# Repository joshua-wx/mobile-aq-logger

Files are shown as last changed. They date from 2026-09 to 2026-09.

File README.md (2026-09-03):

# AQ Rapid Sampler

A portable air-quality logger built on an ESP32-S3 running MicroPython. A
Sensirion SEN65 samples particulate matter and gas indices once a second; a
battery-backed PCF8523 real-time clock timestamps every row; readings go to a
CSV file on the board's flash.

The device has no WiFi and no web server. Its whole interface is a
line-oriented JSON protocol on the USB serial port, and one dashboard —
[`aq_bridge.py`](aq_bridge.py) on a host computer at `http://127.0.0.1:9876` —
both displays it and drives it:

| | |
|---|---|
| **Display** | Live readings, the last 200 samples, 30-minute plots of every variable |
| **Control** | Start/stop logging, set location, set the clock, download (one file or all of them) and delete log files |

Logging does not need the host. Location and the autostart flag are persisted
on the device, so a board configured at the bench can be unplugged and run on
battery; a run already in progress continues when the USB cable comes out.

---

## Hardware

ESP32-S3 with two devices on I2C bus 0 at 100 kHz:

```
ESP32-S3            SEN65        PCF8523
--------            -----        -------
GPIO 5  ---- SDA ---- SDA -------- SDA
GPIO 6  ---- SCL ---- SCL -------- SCL
3V3     ---- VCC ---- VCC -------- VCC
GND     ---- GND ---- GND -------- GND
                                   + CR1220 backup cell
```

| Device | Address |
|---|---|
| SEN65 | `0x6B` |
| PCF8523 | `0x68` |

**The PCF8523 and a DS3231 cannot share the bus** — both live at `0x68`. This
project used a DS3231 previously; that support has been removed.

### Two PCF8523 defaults that will bite you

The chip powers up with settings that are wrong for this application, so
[`pcf8523.py`](pcf8523.py) fixes both when you construct the driver:

- **Battery switch-over is disabled** out of reset (`PM = 111`). Until it is
  configured the coin cell does nothing and the clock resets on every power
  cycle. The driver enables standard-mode switch-over with battery-low
  detection, which is correct for a 3.3 V rail and a 3 V cell.
- **CLKOUT runs at 32.768 kHz** out of reset, draining the backup cell for no
  benefit here. The driver turns it off.

⚠️ **Check the crystal on your breakout** and pass `cap_12p5pf=True` (12.5 pF,
e.g. Adafruit's board) or `False` (7 pF). Getting this wrong costs tens of ppm
of timekeeping accuracy.

---

## Files

| File | Role |
|---|---|
| [`main.py`](main.py) | The application. Sampling, logging, clock, and the USB serial protocol. Runs on boot |
| [`sen65.py`](sen65.py) | SEN65 driver, ported from Sensirion's Arduino library |
| [`pcf8523.py`](pcf8523.py) | PCF8523 RTC driver |
| [`aq_bridge.py`](aq_bridge.py) | **Host-side.** Speaks the serial protocol and serves the dashboard |
| [`log_aq.py`](log_aq.py) | Headless alternative to `main.py` — logs to CSV with no host interface at all |
| [`postprocess.ipynb`](postprocess.ipynb) | **Host-side.** Merges a run's hourly CSVs onto one time axis and plots it |
| [`test_sen65.py`](test_sen65.py) | Bench test: print sensor readings once a second |
| [`test_pcf8523.py`](test_pcf8523.py) | Bench test: print the time; set it with `SET_TIME = True` |
| [`boot.py`](boot.py) | MicroPython boot hook, currently all commented out |

---

## Getting started

### 1. Flash the device

Copy to the board's filesystem with `mpremote`, Thonny, or `ampy`:

```
mpremote cp main.py sen65.py pcf8523.py boot.py :
```

Reset the board. It prints its startup banner and begins sampling.

### 2. Start the dashboard

With the board plugged into the host over USB:

```
pip install pyserial
python3 aq_bridge.py                 # auto-detects the board
```

Open `http://127.0.0.1:9876`. Everything below happens there.

### 3. Set the clock

The RTC ships unset, so the first thing to do is give it the time. The Clock
card shows the device time and its drift against the computer you are sitting
at. With **auto** ticked (the default) the page syncs the RTC by itself
whenever the clock is unset or more than 10 s out; the button does the same on
demand.

If the card says **"clock not set"** and stays that way after a sync, or reports
**"backup battery low"**, fit a fresh CR1220. Without a working cell the
oscillator-stop flag sets on every power-up and the time never survives a
reboot.

Other ways to set it, if browser accuracy is not enough:

- **A GPS module.** Gives sub-second time *and* the latitude/longitude that is
  typed in by hand today. Most hardware, biggest payoff.
- **`test_pcf8523.py`** with `SET_TIME = True`, flashed once, for a bench set.

### 4. Log

Type the location into the Logging card and press **Save** — it is written to
`config.json` on the device and survives a power cycle, so it only has to be
done when the site changes. Then press **Start logging**. Files appear in the
Log files card for download or deletion.

To deploy the board away from a computer, tick **start logging automatically
at power-up** before unplugging it. The device then opens a new log on every
boot with no host attached. Leave it unticked and logging is started by hand
from the dashboard — a run that is already going keeps going when the USB
cable comes out.

A run rolls over to a new file every hour, so a long deployment arrives as a
row of hourly files rather than one that is slow to transfer. **Download all**
collects the whole row in one go — see *Downloading log files*.

---

## Data format

A new file every hour, and one whenever logging starts, named for its own
start time: `YYYYMMDD_HHMMSS.csv`. Rotation keeps an unattended run from
producing one enormous file, and keeps each file individually downloadable
over the serial link. Change `_ROTATE_S` in [`main.py`](main.py) to use a
different interval, or set it to `0` to write one file per run as before.

```
# Location: lat=-37.8136, lon=144.9631
# Start: 2026-09-02 13:26:46  (elapsed_s = 0)
# Clock: PCF8523 RTC, local time
elapsed_s,PM1.0_ug_m3,PM2.5_ug_m3,PM4.0_ug_m3,PM10_ug_m3,VOC_index,NOx_index
0,7.0,8.0,9.0,10.0,106.0,
1,8.0,9.0,10.0,11.0,107.0,
```

- `elapsed_s` is **whole seconds since the `# Start:` time**, one row per
  second. Absolute time is `Start + elapsed_s`; in pandas, for instance:

  ```python
  df = pd.read_csv(path, comment="#")
  t0 = pd.Timestamp("2026-09-02 13:26:46")          # from the header
  df["timestamp"] = t0 + pd.to_timedelta(df.elapsed_s, unit="s")
  ```

  `start + elapsed_s` is exactly the row's wall-clock second: the header time,
  the filename and the offset origin all come from one reading of the clock,
  so hourly files stitch back together without a seam.

- The start time is **local wall-clock with no timezone**.
- Empty fields are readings the sensor did not supply. NOx in particular stays
  blank for the first minutes while its index warms up.
- The `# Clock:` line records whether the start time can be trusted. If the RTC
  is unset or absent it says so explicitly rather than letting you discover it
  later.
- Roughly **64 kB per 35 minutes**, so about 45 hours in 8 MB, split across
  one file per hour of about 110 kB each — less the reserve described below,
  which stops logging before the filesystem is full.
- Every file stands alone: its own location, start time, clock provenance and
  `elapsed_s` origin. Rotation happens *before* the sample that triggers it is
  written, so that sample opens the new file rather than being lost or
  recorded twice — no row falls in a crack between two files.
- A file is never overwritten. If the clock is stopped and hands out a name
  that already exists — the same second on every boot, with a flat RTC — the
  new log becomes `20260902_211719-1.csv`, `-2.csv` and so on rather than
  clobbering what is there.

The column was a full `YYYY-MM-DD HH:MM:SS` timestamp until it became clear it
was ~40% of every row and entirely redundant: at a fixed 1 Hz it is
reconstructible from the start time. That change alone took the same log from
96 kB to 64 kB.

Two clock effects are worth knowing about. The periodic RTC resync can step
the clock by a second or two, and `elapsed_s` follows it — that is the point,
since it is correcting the ESP32's RC drift, so the column tracks real elapsed
time rather than a drifting oscillator. Setting the clock from the dashboard
mid-run does **not** dislocate the column: the logging epoch moves with the
correction, so a run that starts before the clock is set stays continuous.

### When the flash fills up

Logging stops by itself while **128 kB is still free**, rather than running the
filesystem to zero.

The reserve is sized around what is on that filesystem besides data: the
device's own source. `main.py`, `sen65.py`, `pcf8523.py` and `boot.py` come to
about 45 kB together, so 128 kB leaves room to rewrite every one of them over
USB with ~85 kB spare for filesystem metadata and headroom. A flash filled to
the last byte is one you cannot repair without first deleting data — which is
the situation the reserve exists to avoid. It costs 1.6% of an 8 MB flash, or
about 70 minutes of logging out of ~45 hours.

Change `_MIN_FREE_B` in [`main.py`](main.py) to use a different figure. If you
are on a larger flash, or you never intend to reflash over USB, a smaller
reserve is perfectly reasonable — 32 kB still covers filesystem metadata
comfortably.

- Free space is checked **once a minute** while logging, not once a second:
  `statvfs` has to walk filesystem metadata, and a minute of logging is under
  2 kB against a 128 kB reserve, so nothing can slip past between checks.
- **Starting** a log is refused the same way, with the numbers in the reply,
  so a device that cannot log says so rather than appearing to start.
- Sampling, the live stream and the dashboard all keep running. Only writing
  to flash stops.
- The device card shows free space in amber as it approaches the reserve and
  red once logging is barred, and the Logging card shows **STOPPED** with the
  reason rather than an unexplained **IDLE**.
- If `statvfs` is unavailable the check does nothing: the logger will not stop
  on an absence of evidence.

Free some space by downloading and deleting log files from the dashboard, and
logging can start again.

### Reading the gas indices

VOC and NOx are Sensirion index values, not concentrations, and **they do not
share a baseline**:

| | Range | Resting value | Meaning |
|---|---|---|---|
| VOC index | 1–500 | **100** | Moves either side of 100 as VOCs rise and fall |
| NOx index | 1–500 | **1** | Sits at 1 and only climbs when NOx is present |

So a NOx column that reads a constant `1.0` is the sensor saying "no NOx above
baseline" — it is not a fault. In a 35-minute indoor test log, NOx was blank
for 9 s, then 0 for 46 s, then 1.0 for the remaining 2076 samples without once
moving, while VOC climbed from 0 and settled at 100.

Both indices read 0 for about the first minute while the algorithm establishes
itself, and are blank for the first few seconds before that.

### Where time comes from

The PCF8523 seeds the ESP32's internal clock at boot; timestamps are then taken
from the internal clock so the shared I2C bus is not hit once per sample; and
the internal clock is re-synced from the RTC every 10 minutes, because the
ESP32 runs its clock off an RC oscillator that drifts by seconds per hour.

A missing or faulty RTC does not stop the logger. Sampling continues, the
dashboard reports the problem, and the CSV header flags the timestamps as
unreliable.

---

## Postprocessing

An hour per file keeps the device honest and each download small; it also means a
day's run arrives as 24 files that all start their clock at zero.
[`postprocess.ipynb`](postprocess.ipynb) puts them back together:

```
pip install -r requirements-analysis.txt
jupyter lab postprocess.ipynb
```

Point `LOG_DIR` at the folder you unzipped the download into and run the notebook
top to bottom. It recovers each file's start time, location and clock provenance
from its header, turns `elapsed_s` back into absolute time, and merges everything
onto **one continuous time axis** spanning the run.

That axis is built from the cadence the run actually has rather than an assumed
one. A row is written per sensor sample, and the SEN65 does not produce samples on
a perfectly regular beat — a real run comes out around one every two seconds, with
the spacing wandering by a second either way. The notebook measures the typical
interval and treats only a much longer jump as the logger being off, so an hour it
spent switched off is an explicit break every plot honours, while ordinary jitter
is not mistaken for thousands of tiny outages. Set `SAMPLE_PERIOD` to a frequency
like `"1s"` to force a regular grid instead.

It reports the cadence, coverage and gaps, names any file whose `# Clock:` header
the device flagged as unreliable, and draws the run: PM, an hour of PM2.5 zoomed to
individual samples, the gas indices, a panel per variable, an hour-of-day profile
and the distributions, with the WHO 24-hour guideline levels marked. The last cell
writes the merged run out as a single `merged.csv` on that continuous axis, plus an
hourly-mean copy small enough to mail.

---

## The dashboard

On the host computer:

```
pip install pyserial
python3 aq_bridge.py                 # auto-detects the board
```

Then open `http://127.0.0.1:9876`. Device status, logging, the clock and the
location are at the top; live readings, recent samples and plots are tabs
below them.

```
--port /dev/ttyACM0    serial device (default: auto-detect)
--http-port 9876       steps to the next free port if busy
--host 0.0.0.0         let other machines on your network view it
--list                 show candidate serial ports and exit
--no-dtr               see the warning below
--no-map               never fetch map tiles
--tile-cache DIR       where tiles are kept (default: ~/.cache/aq_bridge/tiles)
```

Plot x-axes autoscale to the span of buffered data, clamped between 5 and 30
minutes, with a tick every minute.

⚠️ The dashboard can start and stop logging and **delete files on the device**,
and there is no authentication. It binds to `127.0.0.1` for that reason; only
pass `--host 0.0.0.0` on a network you trust.

### The location map

The Location card shows the saved lat/lon on an OpenStreetMap background, so a
typo in a coordinate is visible rather than something you discover in the data
later. It redraws when the device reports a location — on connection, and
after **Save** — and not on the once-a-second poll.

Tiles are fetched **by the bridge, not by your browser**, and cached under
`~/.cache/aq_bridge/tiles`. That has three consequences worth knowing:

- Displaying a location sends those coordinates to `tile.openstreetmap.org`.
  Nine or so tiles are fetched per location or zoom change, never in bulk, with
  an identifying User-Agent as the [tile usage policy][tup] requires.
- Once an area is cached it keeps working with no connection, so viewing a site
  at the bench means it still draws in the field.
- `--no-map` stops all outbound requests. Cached tiles are still shown; where
  there are none the card falls back to a plain coordinate grid and says so.

The same fallback appears whenever tiles cannot be had — the map is never the
reason you cannot read a coordinate, which is also printed under the card.

[tup]: https://operations.osmfoundation.org/policies/tiles/

### Downloading log files

Log files live on the board's flash — that is what lets it run unattended —
so a download is a transfer over the serial link, not a static file the
browser fetches. Press **Download** and the bridge asks the device for the
file, reassembles the base64 chunks it sends back, checks them against the
byte count and checksum the device reports, and only then hands your browser
a `.csv`. A truncated or corrupted transfer fails with a message instead of
silently saving a short file.

It is not instant: expect a few seconds for a typical log, and longer for a
large one. Sampling and logging continue throughout — the device paces itself
between chunks so a download cannot starve the sensor.

**Download all** does the same for every file on the device and saves them as
a single `aq-logs-<date>-<time>.zip`. It asks the device for a fresh listing
first, so a file opened since the dashboard last refreshed is included, and it
transfers one file at a time — a full flash is minutes of serial, and the Log
files card counts the files off as they arrive. Anything that will not
transfer is left out rather than aborting the run: the zip then carries a
`MISSING.txt` naming those files, and the dashboard says how many were
skipped, so retry them individually with **Download**.

### Serial protocol

`main.py` streams tagged JSON lines and accepts tagged JSON commands on the
same port. Ordinary `print()` diagnostics share it and are ignored by the
reader because they lack the tag.

```
out  AQ1 {"t":"data","ts":"2026-09-02 13:26:45","v":{…},"mx":{…},"mn":{…}}  ~1 Hz
out  AQ1 {"t":"status","lat":-37.8,"logging":true,…}      every 5 s + on change
out  AQ1 {"t":"ack","id":7,"ok":true,"msg":"started"}              per command
out  AQ1 {"t":"file","id":8,"seq":0,"d":"<base64>"}          during a download
in   AQC {"id":7,"cmd":"log_start"}
```

`data` carries the latest / max / 1-minute-mean triple the tables show.
`status` carries configuration, which changes rarely. Every command draws
exactly one `ack` echoing its `id`, so replies can be matched to requests
even though sample records are interleaved with them.

| Command | Fields | Does |
|---|---|---|
| `ping` | — | Liveness check |
| `status` | — | Ask for a `status` record now |
| `list` | — | Files and their sizes |
| `log_start` / `log_stop` | — | Begin or end a logging run |
| `set_loc` | `lat`, `lon` | Set the location and persist it |
| `set_clock` | `ts` (`YYYY-MM-DDTHH:MM:SS`) | Set the RTC and the ESP32 clock |
| `autostart` | `on` | Log automatically at power-up |
| `delete` | `name` | Remove a log file |
| `get` | `name`, `off` | Stream a log file back |

Set `_SERIAL_STREAM = False` in `main.py` to silence the outgoing stream.

**Never send `0x03` (Ctrl-C) on this port.** MicroPython treats it as an
interrupt and would stop the logger. For the same reason, do not leave a REPL
(Thonny, `mpremote`) attached while the bridge is running.

### Persisted configuration

Location and the autostart flag are kept in `config.json` on the device, and
`main.py` reloads them at boot. Deleting that file restores the defaults
compiled into `main.py`.

## Troubleshooting

**Config section fills but the tables and plots stay empty, or data appears
only every few tens of seconds.**
DTR is not asserted. On the ESP32-S3's native USB CDC, DTR is how the host says
"I am listening"; with it low MicroPython treats stdout as disconnected and
truncates it. The signature is lines like `AQ12.2, "pm4p0": 2.8,` — no space
after the tag, starting mid-record. The bridge asserts DTR by default, so this
only happens if you passed `--no-dtr`. Measured on the bench: DTR low gave 0
parseable records in 12 s, DTR high gave 14 with zero errors.

**Garbled lines, or "device reports readiness to read but returned no data".**
Two programs are reading the port. Linux lets several processes open the same
tty and then splits the bytes between them, corrupting every line for all of
them — and an `open()` test cannot detect this, because it succeeds anyway.
Close Thonny, `mpremote`, and any second bridge. The bridge now opens the port
exclusively, so a second copy fails cleanly instead of stealing bytes.

**`OSError: [Errno 98] Address already in use`.**
Something else on the machine holds the HTTP port. Find it with
`ss -ltnp | grep :9876`, or just pass `--http-port`.

**The `# Start:` line reads `2000-01-01`.**
The RTC has never been set, or its backup cell is flat, so the ESP32 is running
from its power-on epoch. See *Set the clock* above. A board deployed with
autostart and a flat cell will still log, and `elapsed_s` is still correct —
only the origin is unknown, and the `# Clock:` line says so.

**Buttons do nothing, or say "no reply from the device in 5 s".**
The device is streaming but not reading commands. Check that nothing else is
holding the port (a REPL will swallow the command bytes), and that `main.py`
is actually running rather than the board sitting at the REPL prompt after a
Ctrl-C.

**Logging stopped on its own and the card says "storage low".**
The flash reached the 128 kB reserve. Download what you want to keep and delete
some log files; logging will start again once there is room. See *When the
flash fills up*.

**A download fails with "transfer stalled" or "checksum mismatch".**
Bytes were lost on the way. Nothing was written to disk — press Download
again. Persistent failures usually mean a second reader on the port. After a
**Download all**, the same failure shows as a file missing from the zip and
named in its `MISSING.txt`.

**`PCF8523 not responding at 0x68`.**
Check wiring. Remember a DS3231 on the bus would answer at the same address.

---

## Known limitations

- Times are local wall-clock with **no timezone recorded**. A log moved between
  machines carries no indication of which offset it was taken in.
- **The device cannot be configured in the field.** With the WiFi dashboard
  gone, setting the clock or the location needs a computer and a USB cable;
  a phone will not do. Configure at the bench, and rely on `config.json` and
  the autostart flag once deployed. Only start/stop is lost in the field, and
  autostart covers the common case.
- The bridge has **no authentication**, so it binds to localhost by default.
- The map is a fixed north-up view with zoom buttons; it cannot be panned, and
  clicking it does not set the location.
- Location is entered by hand, not sensed.
- The SEN65 also reports **temperature and relative humidity**, which the driver
  exposes but nothing currently logs or displays.
- Browser sync sets the clock to about a second; there is no round-trip latency
  compensation.
- Downloads transfer the whole file each time. `get` accepts an `off` offset so
  a resume is possible, but the dashboard does not use it.

---

## Licence

[MIT](LICENSE).

[`sen65.py`](sen65.py) is a port of Sensirion's Arduino I2C library for the
SEN6x family; command IDs, execution delays and scaling factors come from their
published driver. Sensirion's originals are BSD-3-Clause.

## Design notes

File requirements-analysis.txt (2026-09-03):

# Host-side only, for postprocess.ipynb. Nothing here is installed on the ESP32,
# and none of it is needed to run the logger or the dashboard.
pandas>=2.0
matplotlib>=3.7
jupyterlab>=4.0

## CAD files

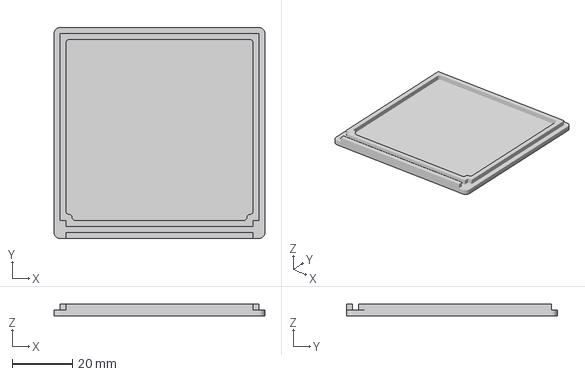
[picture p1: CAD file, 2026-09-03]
case/sen66caselid.3mf
70.0 x 70.0 x 4.00 mm

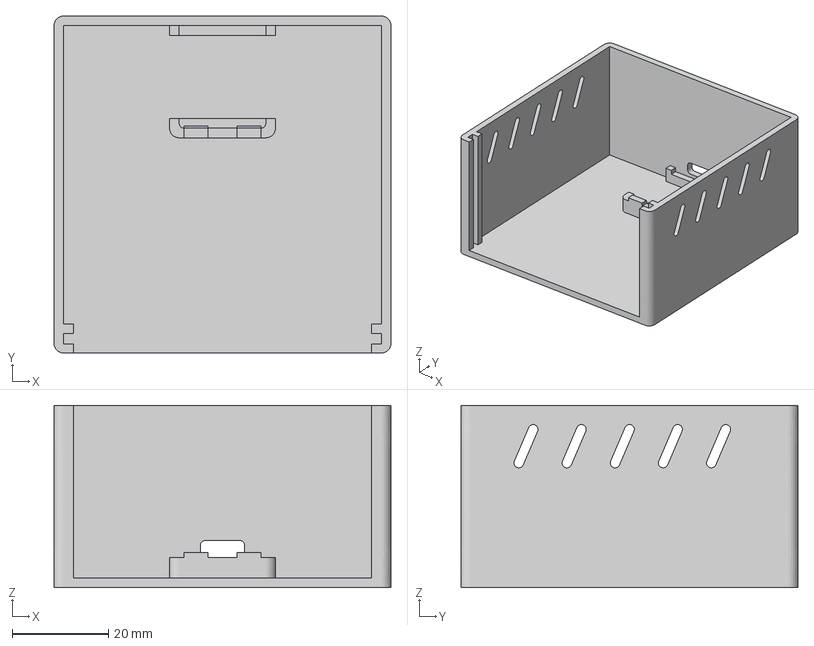
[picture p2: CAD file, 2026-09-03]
case/sen66casebase.3mf
70.0 x 70.0 x 37.9 mm

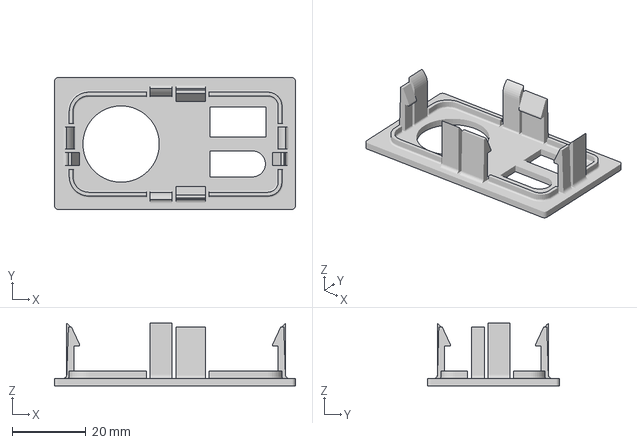
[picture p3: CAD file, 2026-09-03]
case/sen66bracket.3mf
65.5 x 35.9 x 17.0 mm

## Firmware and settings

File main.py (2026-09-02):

"""
AQ-logger — MicroPython air-quality logger for ESP32-S3.

Samples a Sensirion SEN65 once a second, timestamps every row from a
battery-backed PCF8523 RTC, and appends to a CSV file on the board's flash.
A new file is started every hour so an unattended run does not produce one
unbounded file; see _ROTATE_S.

There is no WiFi and no web server here. The device's entire interface is a
line-oriented protocol on the USB serial port: it streams tagged JSON out and
accepts tagged JSON commands in. aq_bridge.py on a host computer speaks that
protocol and serves the one dashboard, which both displays readings and
configures the device — location, clock, start/stop logging, and downloading
or deleting log files.

Logging does not need the host. Configuration is persisted to config.json, so
a device set up at the bench keeps its location and, if autostart is enabled,
begins logging by itself on power-up. Unplugging the host does not interrupt
a run in progress.

Wire format. One record per line, so a reader can use readline() and ignore
anything it does not recognise:

    out   AQ1 {"t":"data","ts":"...","v":{...},"mx":{...},"mn":{...}}  ~1 Hz
    out   AQ1 {"t":"status","lat":-37.8,"logging":true,...}       every 5 s
    out   AQ1 {"t":"ack","id":7,"ok":true,"msg":"started"}      per command
    out   AQ1 {"t":"file","id":8,"seq":0,"d":"<base64>"}     during download
    in    AQC {"id":7,"cmd":"log_start"}

Ordinary print() diagnostics share the port; they simply lack the tag.

Never send 0x03 (Ctrl-C) on this port: MicroPython treats it as an interrupt
and would stop the logger. Commands are plain ASCII JSON lines.

Wiring (I2C bus 0):
    SDA -> GPIO 5
    SCL -> GPIO 6
    SEN65 at 0x6B, PCF8523 at 0x68
"""

try:
    import asyncio
except ImportError:
    import uasyncio as asyncio   # MicroPython < 1.19

try:
    import json
except ImportError:
    import ujson as json

try:
    import select
except ImportError:
    import uselect as select

try:
    import binascii
except ImportError:
    import ubinascii as binascii

import os
import sys
import time
from machine import I2C, Pin, RTC

from pcf8523 import PCF8523
from sen65 import SEN65

# ---------------------------------------------------------------------------
# Constants
# ---------------------------------------------------------------------------

_KEYS       = ('pm1p0', 'pm2p5', 'pm4p0', 'pm10p0', 'voc', 'nox')
# Rows carry seconds elapsed since '# Start:' in the header rather than a
# full timestamp: at 1 Hz the absolute time was ~40% of every row and is
# entirely reconstructible from the start time plus the offset.
_CSV_HEADER = 'elapsed_s,PM1.0_ug_m3,PM2.5_ug_m3,PM4.0_ug_m3,PM10_ug_m3,VOC_index,NOx_index\n'

_ROTATE_S    = 3600     # start a new log file this often; 0 disables rotation

# Stop logging while this much of the filesystem is still free. The board's
# own source lives on that filesystem — main.py, sen65.py, pcf8523.py and
# boot.py are ~45 kB together — so the reserve is sized to let every one of
# them be rewritten over USB, with the rest as headroom for filesystem
# metadata. Filling the flash completely would leave no room to repair the
# device without first deleting data. Costs ~1.6% of an 8 MB flash.
_MIN_FREE_B    = 128 * 1024
_SPACE_CHECK_S = 60     # how often to look at free space while logging
_RESYNC_S    = 600      # re-read the PCF8523 into the ESP32 clock this often
_DRIFT_WARN  = 2        # seconds of MCU-vs-RTC drift worth printing

_SERIAL_STREAM   = True   # emit tagged JSON lines on USB serial
_SERIAL_TAG      = 'AQ1'  # prefix on every line this device emits
_CMD_TAG         = 'AQC'  # prefix the host puts on every command
_SERIAL_STATUS_S = 5      # seconds between unsolicited 'status' records

_CONFIG_FILE = 'config.json'

# File download tuning. 512 raw bytes become a ~700-character line; the pause
# hands the scheduler back to the sensor task between chunks so a download
# cannot starve sampling, and keeps the USB CDC buffer from backing up into a
# blocking write.
_CHUNK        = 512
_CHUNK_PAUSE  = 4         # ms between chunks
_CMD_MAX_LINE = 512       # longest command line accepted, then resynchronise

# ---------------------------------------------------------------------------
# Global state
# ---------------------------------------------------------------------------

_g = {
    'latest':  {k: None for k in _KEYS},
    'max':     {k: None for k in _KEYS},
    'ring':    [],        # last <=60 readings for 1-min mean
    'logging': False,
    'logfile': None,
    'log_t0': None,       # time.time() at the start of the current run
    'stop_reason': '',    # why logging last stopped, '' if by request
    'space_at': 0,        # when free space was last checked
    'ts':      '--',
    'lat':     -37.8136,
    'lon':     144.9631,
    'autostart': False,   # begin logging at boot without a host attached
    'boot_ms': 0,
    'rtc':     None,      # PCF8523 instance, or None if it did not answer
    'rtc_ok':  False,     # False while the RTC reports a stopped oscillator
    'batt_low': False,
    'sending': False,     # a file download is in flight
}

# ---------------------------------------------------------------------------
# Helpers
# ---------------------------------------------------------------------------

def _fmt(v):
    return '' if v is None else '{:.1f}'.format(v)

def _timestamp(t=None):
    """Local wall-clock time as 'YYYY-MM-DD HH:MM:SS'.

    Takes an optional epoch so a log's header, filename and elapsed_s origin
    can all be derived from one instant; reading the clock three times risks
    the second ticking between them, which would put every reconstructed row
    time out by one.
    """
    y, mo, d, h, mi, s = (time.localtime() if t is None else time.localtime(t))[:6]
    return '{:04d}-{:02d}-{:02d} {:02d}:{:02d}:{:02d}'.format(y, mo, d, h, mi, s)

def _filename(t=None):
    y, mo, d, h, mi, s = (time.localtime() if t is None else time.localtime(t))[:6]
    return '{:04d}{:02d}{:02d}_{:02d}{:02d}{:02d}.csv'.format(y, mo, d, h, mi, s)

def _compute_mean(ring):
    if not ring:
        return {k: None for k in _KEYS}
    out = {}
    for k in _KEYS:
        vals = [r[k] for r in ring if r[k] is not None]
        out[k] = round(sum(vals) / len(vals), 1) if vals else None
    return out

def _round1(d):
    return {k: (round(v, 1) if v is not None else None) for k, v in d.items()}

def _list_files():
    """[[name, bytes], ...] for every CSV on flash, oldest name first."""
    out = []
    for f in sorted(os.listdir()):
        if f.endswith('.csv'):
            try:
                out.append([f, os.stat(f)[6]])
            except OSError:
                pass
    return out

def _free_bytes():
    try:
        st = os.statvfs('/')
        return st[0] * st[3]
    except (OSError, AttributeError):
        return None

# ---------------------------------------------------------------------------
# Persisted configuration
#
# With the WiFi dashboard gone the device cannot be reconfigured in the
# field, so what was typed in at the bench has to survive a power cycle.
# ---------------------------------------------------------------------------

def _load_config():
    try:
        with open(_CONFIG_FILE) as fh:
            cfg = json.load(fh)
    except (OSError, ValueError):
        return
    for key in ('lat', 'lon'):
        v = cfg.get(key)
        if isinstance(v, (int, float)):
            _g[key] = float(v)
    _g['autostart'] = bool(cfg.get('autostart', False))

def _save_config():
    try:
        with open(_CONFIG_FILE, 'w') as fh:
            json.dump({'lat': _g['lat'], 'lon': _g['lon'],
                       'autostart': _g['autostart']}, fh)
        return True
    except OSError as e:
        print('Config save failed:', e)
        return False

# ---------------------------------------------------------------------------
# Serial output
# ---------------------------------------------------------------------------

def _emit(kind, obj):
    if not _SERIAL_STREAM:
        return
    obj['t'] = kind
    try:
        print(_SERIAL_TAG, json.dumps(obj))
    except Exception as e:      # a blocked port must never stop the logger
        print('Serial emit failed:', e)


def _emit_status():
    _emit('status', {
        'ts':          _timestamp(),
        'lat':         _g['lat'],
        'lon':         _g['lon'],
        'logging':     _g['logging'],
        'logfile':     _g['logfile'] or '',
        'autostart':   _g['autostart'],
        'stop_reason': _g['stop_reason'],
        'min_free':    _MIN_FREE_B,
        'rtc_present': _g['rtc'] is not None,
        'rtc_ok':      _g['rtc_ok'],
        'batt_low':    _g['batt_low'],
        'files':       _list_files(),
        'free':        _free_bytes(),
        'up':          time.ticks_diff(time.ticks_ms(), _g['boot_ms']) // 1000,
    })


def _ack(cid, ok, msg, data=None):
    rec = {'id': cid, 'ok': ok, 'msg': msg}
    if data is not None:
        rec['data'] = data
    _emit('ack', rec)


async def _status_task():
    while True:
        _emit_status()
        await asyncio.sleep(_SERIAL_STATUS_S)


# ---------------------------------------------------------------------------
# Clock
# ---------------------------------------------------------------------------

def _open_rtc(i2c):
    """Attach to the PCF8523 and seed the ESP32 clock from it.

    A missing or faulty RTC must not stop the logger: the sensor still runs
    and the dashboard reports the problem, timestamps just start from
    whatever the ESP32 booted with until the host sets the clock.
    """
    try:
        rtc = PCF8523(i2c)
    except OSError as e:
        print('WARNING: PCF8523 not responding at 0x68 ({}) - running without it.'.format(e))
        return None

    _g['rtc'] = rtc
    if not _sync_mcu_clock(rtc):
        print('WARNING: PCF8523 oscillator stopped - time is not trustworthy.')
        print('         Connect the host bridge and sync the clock.')
    if _g['batt_low']:
        print('WARNING: PCF8523 backup battery is low - replace the cell.')
    return rtc


def _sync_mcu_clock(rtc):
    """Copy RTC -> ESP32 internal clock. Returns True if the time is valid.

    The ESP32 runs its clock off an RC oscillator that drifts by seconds per
    hour, so this is called periodically, not just at boot.
    """
    try:
        _g['rtc_ok']   = not rtc.lost_power()
        _g['batt_low'] = rtc.battery_low()
        if _g['rtc_ok']:
            RTC().datetime(rtc.datetime())
    except OSError as e:
        print('RTC read failed:', e)
        return False
    return _g['rtc_ok']


def _set_clock(rtc, dt):
    """Set both the PCF8523 and the ESP32 clock from an 8-tuple."""
    before = int(time.time())
    RTC().datetime(dt)
    # Setting the clock redefines the time base — often by years, when the
    # RTC was unset. Carry the logging epoch along with it so elapsed_s stays
    # continuous instead of jumping the width of the correction. The periodic
    # RTC resync is deliberately not compensated: those steps are the drift
    # correction, and elapsed_s should follow them.
    if _g['log_t0'] is not None:
        _g['log_t0'] += int(time.time()) - before
    if rtc is not None:
        rtc.datetime(dt)
        _g['rtc_ok']   = not rtc.lost_power()
        _g['batt_low'] = rtc.battery_low()
    return _g['rtc_ok']


async def _clock_task():
    """Pull the ESP32 clock back onto the RTC every _RESYNC_S seconds."""
    while True:
        await asyncio.sleep(_RESYNC_S)
        rtc = _g['rtc']
        if rtc is None:
            continue
        try:
            before = time.time()
            if _sync_mcu_clock(rtc):
                drift = time.time() - before
                if abs(drift) >= _DRIFT_WARN:
                    print('Clock resync: stepped MCU clock by {:+d} s'.format(drift))
        except Exception as e:
            print('Clock resync failed:', e)


# ---------------------------------------------------------------------------
# Radio
# ---------------------------------------------------------------------------

def _radio_off():
    """Shut the WiFi down. Nothing uses it, and this is a battery device.

    The interface state can survive a soft reset, so an AP left running by a
    previous firmware would otherwise keep drawing current forever.
    """
    try:
        import network
        for iface in (network.AP_IF, network.STA_IF):
            w = network.WLAN(iface)
            if w.active():
                w.active(False)
    except Exception as e:
        print('Could not disable WiFi:', e)


# ---------------------------------------------------------------------------
# Logging
# ---------------------------------------------------------------------------

def _open_log():
    """Create a new CSV, write its header, and make it the active log.

    Returns (filename, message), or (None, reason) if it could not be
    opened. Every file is self-contained: its own location, start time and
    clock provenance, with elapsed_s counting from zero again.
    """
    free = _free_bytes()
    if free is not None and free < _MIN_FREE_B:
        return None, 'storage low: {} kB free, {} kB reserved'.format(
            free // 1024, _MIN_FREE_B // 1024)
    # One instant for the name, the header and the elapsed_s origin, kept as
    # whole seconds so that start + elapsed_s is exactly the row's wall clock.
    t0 = int(time.time())
    fname = _filename(t0)
    # A stopped RTC hands out the same name on every boot, which would
    # otherwise silently overwrite the previous run's data.
    stem, n = fname[:-4], 1
    while n < 100:
        try:
            os.stat(fname)
        except OSError:
            break                       # the name is free
        fname = '{}-{}.csv'.format(stem, n)
        n += 1
    try:
        with open(fname, 'w') as fh:
            if _g['lat'] is not None:
                fh.write('# Location: lat={}, lon={}\n'.format(_g['lat'], _g['lon']))
            fh.write('# Start: {}  (elapsed_s = 0)\n'.format(_timestamp(t0)))
            # Timestamps are local wall-clock with no timezone, so record
            # where they came from and whether they can be believed.
            if _g['rtc'] is None:
                clock = 'ESP32 internal only, no RTC - times unreliable'
            elif not _g['rtc_ok']:
                clock = 'PCF8523 RTC NOT SET - times unreliable'
            else:
                clock = 'PCF8523 RTC, local time'
            fh.write('# Clock: {}\n'.format(clock))
            fh.write(_CSV_HEADER)
    except OSError as e:
        print('Could not open log file:', e)
        return None, str(e)
    _g['logfile'] = fname
    _g['log_t0']  = t0
    return fname, 'started'


def _start_logging():
    if _g['logging']:
        return _g['logfile'], 'already logging'
    fname, msg = _open_log()
    if fname is None:
        return None, msg
    _g['logging'] = True
    _g['stop_reason'] = ''
    _g['space_at'] = time.time()
    print('Logging started:', fname)
    return fname, msg


def _stop_logging(reason=''):
    """Stop the run. `reason` is empty when a person asked for it."""
    if _g['logging']:
        print('Logging stopped:', _g['logfile'],
              '({})'.format(reason) if reason else '')
        _g['logging'] = False
        _g['stop_reason'] = reason


# ---------------------------------------------------------------------------
# Commands
#
# One JSON object per line, tagged so that terminal noise and half-typed
# input are ignored rather than misread:
#
#     AQC {"id":7,"cmd":"log_start"}
#
# Every command draws exactly one 'ack' carrying the same id, so the host can
# match replies to requests even though status and data records are
# interleaved with them. 'get' acks first and then streams 'file' records.
# ---------------------------------------------------------------------------

def _cmd_set_loc(c):
    try:
        lat = float(c['lat'])
        lon = float(c['lon'])
    except (KeyError, TypeError, ValueError):
        return False, 'invalid lat/lon', None
    if not (-90.0 <= lat <= 90.0) or not (-180.0 <= lon <= 180.0):
        return False, 'lat/lon out of range', None
    _g['lat'] = lat
    _g['lon'] = lon
    saved = _save_config()
    return True, 'saved {:.6f}, {:.6f}{}'.format(
        lat, lon, '' if saved else ' (not persisted)'), None


def _cmd_set_clock(c):
    try:
        s = c['ts']                    # "2026-06-11T14:30:00"
        date, t = s.split('T')
        y, mo, d = date.split('-')
        h, mi, sec = t.split(':')
        dt = (int(y), int(mo), int(d), 0, int(h), int(mi), int(sec), 0)
    except (KeyError, TypeError, ValueError, AttributeError) as e:
        return False, 'invalid datetime: ' + str(e), None

    try:
        ok = _set_clock(_g['rtc'], dt)
    except (OSError, ValueError) as e:
        return False, 'RTC write failed: ' + str(e), None

    print('Clock set to:', s)
    if _g['rtc'] is None:
        return True, 'ESP32 clock set (no RTC): ' + s, None
    if not ok:
        return False, 'RTC written but oscillator still stopped - check the battery', None
    return True, 'clock set: ' + s, None


def _cmd_autostart(c):
    _g['autostart'] = bool(c.get('on'))
    saved = _save_config()
    return (saved,
            'autostart {}{}'.format('on' if _g['autostart'] else 'off',
                                    '' if saved else ' (not persisted)'),
            None)


def _cmd_delete(c):
    name = c.get('name')
    if not isinstance(name, str) or '/' in name or not name.endswith('.csv'):
        return False, 'invalid filename', None
    if _g['logging'] and _g['logfile'] == name:
        return False, 'cannot delete the active log file', None
    try:
        os.remove(name)
    except OSError:
        return False, 'not found', None
    print('Deleted:', name)
    return True, 'deleted ' + name, None


async def _send_file(cid, c):
    """Stream one CSV back as base64 'file' records, then an eof record.

    The host verifies what arrived against the byte count and checksum in
    the eof record, so a chunk lost to a serial hiccup is detected rather
    than silently producing a short file. 'off' lets it resume instead of
    starting the whole transfer again.
    """
    name = c.get('name')
    if not isinstance(name, str) or '/' in name or not name.endswith('.csv'):
        _ack(cid, False, 'invalid filename')
        return
    try:
        off = int(c.get('off', 0))
    except (TypeError, ValueError):
        off = 0
    try:
        size = os.stat(name)[6]
    except OSError:
        _ack(cid, False, 'not found')
        return
    if _g['sending']:
        _ack(cid, False, 'another download is in progress')
        return

    _g['sending'] = True
    _ack(cid, True, 'sending', {'name': name, 'size': size, 'off': off})
    total = 0
    csum  = 0
    seq   = 0
    try:
        with open(name, 'rb') as fh:
            if off:
                fh.seek(off)
            while True:
                chunk = fh.read(_CHUNK)
                if not chunk:
                    break
                csum   = (csum + sum(chunk)) & 0xFFFFFFFF
                total += len(chunk)
                _emit('file', {
                    'id':  cid,
                    'seq': seq,
                    'd':   binascii.b2a_base64(chunk).decode().strip(),
                })
                seq += 1
                await asyncio.sleep_ms(_CHUNK_PAUSE)
    except OSError as e:
        _emit('file', {'id': cid, 'eof': True, 'err': str(e),
                       'n': total, 'sum': csum})
        return
    finally:
        _g['sending'] = False
    _emit('file', {'id': cid, 'eof': True, 'n': total, 'sum': csum})


async def _handle_command(line):
    """Dispatch one already-untagged JSON command line."""
    try:
        c = json.loads(line)
    except ValueError:
        _emit('ack', {'id': None, 'ok': False, 'msg': 'malformed JSON'})
        return
    if not isinstance(c, dict):
        _emit('ack', {'id': None, 'ok': False, 'msg': 'not an object'})
        return

    cid  = c.get('id')
    name = c.get('cmd')

    if name == 'get':
        await _send_file(cid, c)
        return

    if name == 'ping':
        ok, msg, data = True, 'pong', None
    elif name == 'status':
        ok, msg, data = True, 'status', None
    elif name == 'log_start':
        fname, msg = _start_logging()
        ok, data = fname is not None, {'logfile': fname} if fname else None
    elif name == 'log_stop':
        _stop_logging()
        ok, msg, data = True, 'stopped', None
    elif name == 'set_loc':
        ok, msg, data = _cmd_set_loc(c)
    elif name == 'set_clock':
        ok, msg, data = _cmd_set_clock(c)
    elif name == 'autostart':
        ok, msg, data = _cmd_autostart(c)
    elif name == 'list':
        ok, msg, data = True, 'files', {'files': _list_files()}
    elif name == 'delete':
        ok, msg, data = _cmd_delete(c)
    else:
        _ack(cid, False, 'unknown command: {}'.format(name))
        return

    _ack(cid, ok, msg, data)
    # Every command either changes configuration or is a request to see it,
    # so refresh the host immediately rather than up to 5 s later.
    _emit_status()
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

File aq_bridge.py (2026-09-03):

#!/usr/bin/env python3
"""
USB-serial to web bridge for the AQ-logger — the device's only interface.

Runs on a host computer, reads the tagged JSON lines main.py streams over USB
serial, and serves a dashboard at http://127.0.0.1:9876 that both displays the
readings and configures the device: location, clock, start/stop logging, and
downloading or deleting the CSV log files held on the board's flash.

The device has no WiFi and no web server of its own. Commands travel back up
the same serial line as tagged JSON, each carrying an id the device echoes in
its reply, so a button press can be matched to its answer even though sample
and status records are interleaved with it. Downloads come back as base64
chunks that are reassembled and checked here before the browser sees a file.

    pip install pyserial
    python3 aq_bridge.py                  # auto-detect the board
    python3 aq_bridge.py --port /dev/ttyACM0
    python3 aq_bridge.py --list           # show candidate ports and exit

The dashboard defaults to port 9876 rather than 8000, which is heavily
contested (nginx, Django, python -m http.server). If it is taken anyway the
bridge steps to the next free port and tells you which one it used.

It binds to 127.0.0.1 by default. --host 0.0.0.0 exposes the dashboard to your
network, and the dashboard can now change the device and delete its files, so
only do that on a network you trust: there is no authentication.

DTR is asserted on open. On an ESP32-S3's native USB CDC that is how the host
says "I am listening": with DTR low, MicroPython treats stdout as
disconnected and truncates it, so records arrive shredded or not at all.
RTS is left low, which is what an ordinary terminal does and does not reset
the board. --no-dtr exists for the rare adapter that auto-resets on DTR.

The port is opened exclusively, so a second bridge (or a REPL) fails to
start rather than silently stealing bytes from this one — two readers on one
tty corrupt the stream for both.
"""

import argparse
import base64
import errno
import io
import json
import os
import re
import sys
import threading
import time
import urllib.error
import urllib.request
import zipfile
from collections import deque
from http.server import BaseHTTPRequestHandler, ThreadingHTTPServer
from urllib.parse import urlparse, parse_qs

try:
    import serial
    from serial.tools import list_ports
except ImportError:
    sys.exit("pyserial is required:  pip install pyserial")

TAG = "AQ1"          # every line the device emits
CMD_TAG = "AQC"      # every line the bridge sends
KEYS = ("pm1p0", "pm2p5", "pm4p0", "pm10p0", "voc", "nox")
NAMES = ("PM1.0", "PM2.5", "PM4.0", "PM10", "VOC", "NOx")
UNITS = ("µg/m³", "µg/m³", "µg/m³", "µg/m³",
         "index", "index")

PLOT_SECONDS = 30 * 60      # widest the plot x-axis ever gets
MIN_PLOT_SECONDS = 5 * 60   # narrowest, so a fresh start is not a single dot
TABLE_ROWS = 200            # history table shows the last 200 samples
# 30 min at ~1 Hz, with headroom so a faster sensor cannot truncate the window.
HISTORY = PLOT_SECONDS * 2

# Espressif USB VIDs plus the usual USB-UART bridges, best guess first.
_USB_VIDS = (0x303A, 0x10C4, 0x1A86, 0x0403, 0x2341)

# Commands the dashboard may send. Anything else is refused here rather than
# forwarded, so a stray POST cannot reach the device.
ALLOWED_COMMANDS = frozenset((
    "ping", "status", "list", "log_start", "log_stop",
    "set_loc", "set_clock", "autostart", "delete",
))

# --- map tiles ------------------------------------------------------------
# The page asks this bridge for tiles, never OpenStreetMap directly: one place
# to identify ourselves, one disk cache, and the browser makes no third-party
# requests. Only the tiles around a saved location are ever fetched — nine or
# so per location change — and they are reused from disk after that, so a
# laptop taken into the field keeps showing sites it has already displayed.
TILE_URL = "https://tile.openstreetmap.org/%d/%d/%d.png"
TILE_UA = ("aq_bridge.py/1.0 (AQ-logger dashboard; single-user local tool; "
           "https://www.openstreetmap.org/copyright)")
TILE_TIMEOUT = 8.0
TILE_MAX_Z = 19
TILE_CACHE = os.path.join(
    os.environ.get("XDG_CACHE_HOME") or os.path.expanduser("~/.cache"),
    "aq_bridge", "tiles")
# Two at a time is plenty for a nine-tile view and keeps us well inside the
# OSM tile usage policy.
TILE_SEM = threading.Semaphore(2)
TILE_FETCH = True          # cleared by --no-map
TILE_FAILED = {}           # (z,x,y) -> when, so a dead network is not hammered
TILE_FAIL_TTL = 60.0
TILE_LOCK = threading.Lock()

CMD_TIMEOUT = 5.0        # seconds to wait for an ack
FILE_TIMEOUT = 300.0     # ceiling on a whole download
FILE_IDLE = 10.0         # a download with no chunk for this long has stalled
NAME_RE = re.compile(r"^[A-Za-z0-9_.-]+\.csv$")
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

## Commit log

2026-09-02 Replace the WiFi dashboard with a USB serial control surface
    The device had two interfaces: a WiFi AP serving a dashboard that was the
    only place anything could be changed, and a display-only host dashboard fed
    by the USB serial stream. This decommissions the former and moves its
    configuration duties onto the latter, leaving one interface.
    main.py loses the access point, the HTTP server, the embedded page and the
    form-parsing helpers, and gains a command channel on the serial port it was
    already streaming from: tagged JSON in, tagged JSON acks out, correlated by
    id so replies can be matched to requests amid the ~1 Hz sample records.
    WiFi is now explicitly powered down at boot, which is wort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
    [aq_bridge.py, log_aq.py, main.py]
2026-09-02 Stop logging while the flash still has room to operate
    Running the filesystem to zero is not a safe resting state for this device:
    its own source lives there. main.py, sen65.py, pcf8523.py and boot.py come to
    about 45 kB, so a flash filled to the last byte is one that cannot be
    reflashed over USB without first deleting data.
    Logging now stops while 128 kB is still free, which leaves room to rewrite
    every source file with ~85 kB spare for filesystem metadata and headroom. It
    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
2026-09-03 Add the printable enclosure
    Three 3MF models for the case the logger lives in: a base, a lid, and a
    bracket that holds the sensor. Binary, ~73 kB in total, and they change
    rarely, so keeping them alongside the source is more convenient than tracking
    them separately.
    [sen66bracket.3mf, sen66casebase.3mf, sen66caselid.3mf]
2026-09-03 Add a "download all" button to pull every log in one zip
    Retrieving a deployment's logs meant pressing Download once per file, and an
    hourly rollover means a day in the field is a row of them.
    /api/download-all asks the device for a fresh listing rather than reusing the
    last status record, so a file opened since the dashboard refreshed is not left
    behind, fetches each one through the existing verified transfer, and returns a
    single aq-logs-<date>-<time>.zip. One save keeps the browser from tripping its
    own "allow multiple downloads?" guard, and CSV deflates about eightfold.
    A file that will not transfer is skipped rather than aborting the run: on a
    link this slow, throwing away twenty good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
    [aq_bridge.py]
2026-09-03 Add a postprocessing notebook for merging and plotting runs
    An hour per file keeps each download small, but it means a day's run arrives as
    24 files that all start their clock at zero. postprocess.ipynb reads a folder of
    them, recovers each file's start time, location and clock provenance from its
    header, turns elapsed_s back into absolute time, and merges the lot onto one
    continuous time axis.
    That axis follows the cadence the run actually has. A row is written per SEN65
    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
